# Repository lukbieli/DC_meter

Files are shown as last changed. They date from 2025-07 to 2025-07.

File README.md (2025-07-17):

# DC Meter Project (INA219 + ESP32 + OLED + Button)

A complete open-source DC meter for low-power device development, based on ESP32, three INA219 sensors, SSD1306 OLED display, and a capacitive touch button (TTP233).  
Includes firmware, 3D printable enclosure, wiring diagrams, and ready-to-use SerialPlot configuration files.

---

## Features

- Measures voltage, current, and power on up to 3 channels using INA219 sensors.
- Configurable measurement channels (enable/disable voltage, current, power per channel).
- OLED display (SSD1306 64x48) for live readings and demo mode.
- Capacitive touch button (TTP233) for user interaction (mode/channel switching).
- UART communication for data output and command input.
- Supports both raw binary and ASCII print modes for measurement data.
- Periodic measurement with configurable timer period.
- FreeRTOS-based multitasking for measurement and communication.
- Easily configurable I2C pins and addresses via `menuconfig`.
- Optional auto-configuration of INA219 gain and voltage range.
- SerialPlot integration with ready-to-use `.ini` settings files.
- 3D printable enclosure (STL/3MF for Bambu Studio).

    This project supports up to max 1kHz sampling with only one channel enabled.
---

## Bill of Materials (BOM)

| Qty | Part | Description | Link  |
|-----|---|---|---|
| 1 | ESP32 DEVKIT V1 | Main MCU board | [ESP32 DEVKIT V1](https://pl.aliexpress.com/item/1005008127727230.html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) |
| 2 | INA219 Module | Current sensor | [INA219 Module](https://pl.aliexpress.com/item/1005007533576335.html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) |
| 3 | SSD1306 OLED 64x48 | Display (I2C) | [SSD1306 OLED 64x48](https://pl.aliexpress.com/item/1005009104650988.html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) |
| 4 | TTP233 Capacitive Button | Touch button (digital out) | [TTP233](https://pl.aliexpress.com/item/1005007480801162.html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) |
| 5 | 3D Printed Enclosure | STL/3MF files provided | [3D Model](https://cad.onshape.com/documents/d86296f212e362e831ebef51/w/36947445886156c88ad6d59d/e/d64ef3975a24c979aa83f3d0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) |

---

## Wiring & Connections

### ESP32 Pinout

| Signal | ESP32 Pin | Module/Part |
|---|---|---|
| I2C SDA | GPIO 18 | OLED |
| I2C SCL | GPIO 19 | OLED |
| I2C SDA | GPIO 22 | INA219s |
| I2C SCL | GPIO 21 | INA219s |
| Button | GPIO 34 | TTP233 OUT |
| OLED VCC/GND| 3V3/GND | ESP32 |
| INA219 VCC/GND | 3V3/GND | ESP32 |

**Note:**  
- Project uses separate I2C buses to povide conflicts on I2C when measurement period is very small.
- Connect all INA219 to one I2C and OLED to second one.
- Use pull-up resistors (typically 4.7kΩ) on SDA/SCL if not present on modules.
- TTP233 OUT connects to ESP32 GPIO 34 (digital input).

### Example Wiring Diagram

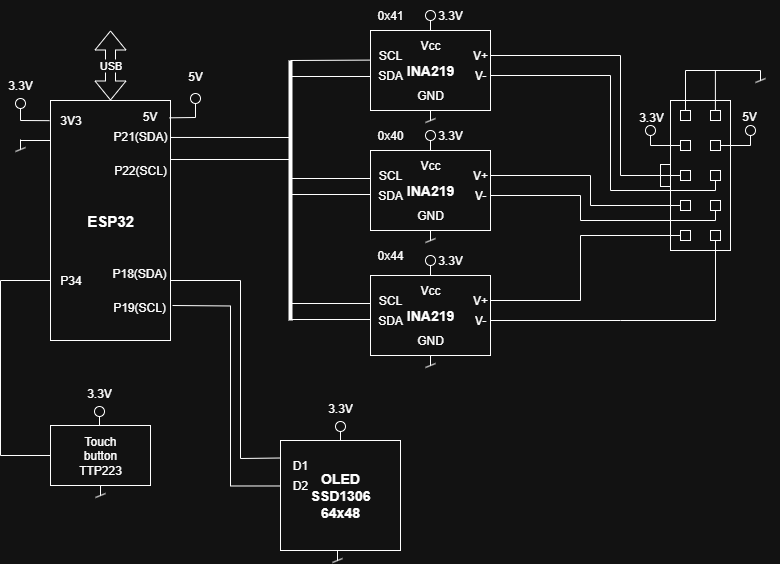
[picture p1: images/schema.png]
Wiring Diagram


---

## Enclosure & 3D Models

- Enclosure designed for ESP32 DEVKIT V1, SSD1306 OLED (64x48), and TTP233 button.
- STL and 3MF files included for Bambu Studio and other slicers.
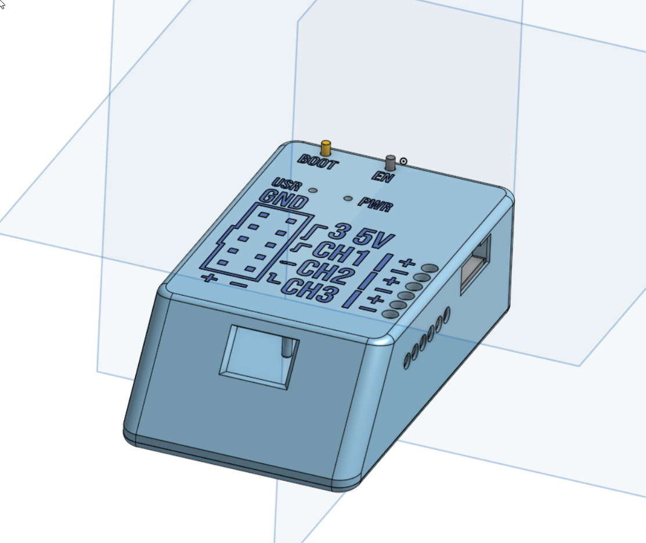
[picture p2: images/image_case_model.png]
3D Model Preview

- [Download 3MF for Bambu Studio](case_model/DC_Meter_Case.3mf)
- [Model available on Onshape.com](https://cad.onshape.com/documents/d86296f212e362e831ebef51/w/36947445886156c88ad6d59d/e/d64ef3975a24c979aa83f3d0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)

---

## SerialPlot Integration

- Ready-to-use SerialPlot `.ini` settings files included:
  - `serialplot/sett_ch9_vcp_default.ini` (raw mode)
  - `serialplot/sett_ch9_vcp_default_ascii.ini` (ASCII mode)
  - `serialplot/sett_ch1_vcp.ini` (single channel example)
- These files configure SerialPlot for live visualization of all channels.
- See [SerialPlot](https://serialplot.org/) for installation.

---

## Firmware Usage

1. **Configure the project** using `idf.py menuconfig`:
    - Set I2C pins, INA219 addresses, shunt resistor value, and LCD options if needed.
2. **Build and flash the firmware**:
    ```sh
    idf.py build
    idf.py flash monitor
    ```
3. **Connect SerialPlot** using the provided `.ini` files for live data plotting.
4. **Button Functions**:
    - Short press: Switch channel (in normal mode).
    - Long press: Switch display mode (demo/normal).

---

## UART Protocol Details

The device communicates over UART using a simple binary protocol for both commands and data.

### Data Output

- **Raw Binary Mode:**  
  Each message starts with two header bytes (`0xAA`, `0xBB`), followed by a length byte, and then the measurement data.  
  The data fields and their order depend on the enabled configuration for each channel (voltage, current, power).  
  - Header: `0xAA 0xBB`
  - Length: Number of data bytes following the header (excluding header and length byte)
  - Data: Floats (4 bytes each) for enabled measurements, in channel order (ch1, ch2, ch3)
- **ASCII Mode:**  
  Each measurement is printed as a comma-separated line of floats:  
  ```
  V1, I1, P1, V2, I2, P2, V3, I3, P3
  ```
  Only enabled measurements are printed.

### Command Input

Commands are sent as binary messages. The first byte is the command type, followed by command-specific data.

| Command Name | Code (hex) | Payload Format | Description |
|---|---|---|---|
| Start/Stop | 0x0A | `[0x0A, 0x01]` or `[0x0A, 0x00]` or `[0x0A, 0x02]` | Start (`0x01`), stop (`0x00`), or start without auto-config (`0x02`) |
| Set Timer Period | 0x0B | `[0x0B, <u8>, <u8>, <u8>, <u8>]`| Set period in microseconds (little-endian)  |
| Set Print Mode | 0x0C | `[0x0C, 0x00]` or `[0x0C, 0x01]`| Raw (`0x00`) or ASCII (`0x01`) output |
| Channel Config | 0x0D | `[0x0D, <ch1>, <cfg1>, <ch2>, <cfg2>, <ch3>, <cfg3>]` | Set channel configuration. See below. |
| Status | 0x0E | `[0x0E]` | Query current status/config |
| Display Mode | 0x0F | `[0x0F, 0x00/0x01]` | Set display mode (normal/demo) |

**Channel Config Bytes:**  
Each channel config consists of two bytes:
- `<chX>`: Bit 0: Voltage enable, Bit 1: Current enable, Bit 2: Power enable
- `<cfgX>`: 
    - Bits 0-1: Gain (0=1, 1=0.5, 2=0.25, 3=0.125)
    - Bit 2: Bus voltage range (0=16V, 1=32V)
    - Bits 4-7: Bus voltage resolution (see `ina219.h` for values)

Example:  
To enable voltage and current for channel 1, only current for channel 2, and all for channel 3:  
`[0x0D, 0x03, 0x10, 0x02, 0x10, 0x07, 0x10]`  
- ch1: 0x03 = 0b011 (voltage+current), 0x10 = gain/resolution config
- ch2: 0x02 = 0b010 (current), 0x10 = gain/resolution config
- ch3: 0x07 = 0b111 (all enabled), 0x10 = gain/resolution config

---

## Images

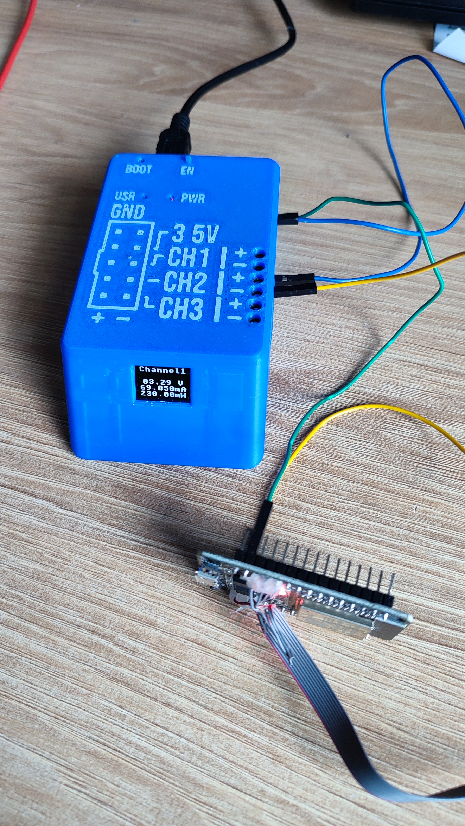
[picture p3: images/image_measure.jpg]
Device Assembled
- 
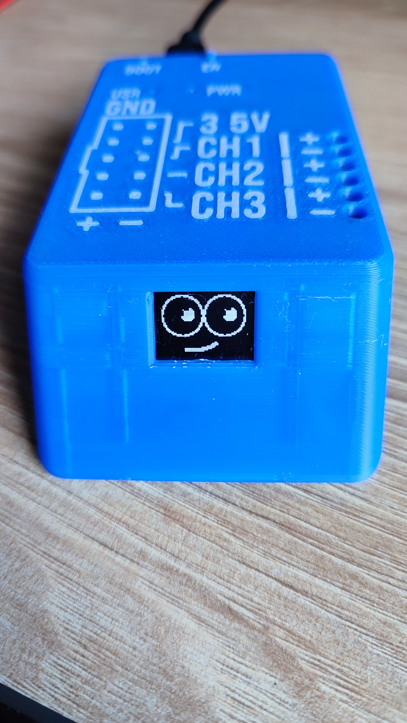
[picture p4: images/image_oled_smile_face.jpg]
OLED Demo Mode
- 
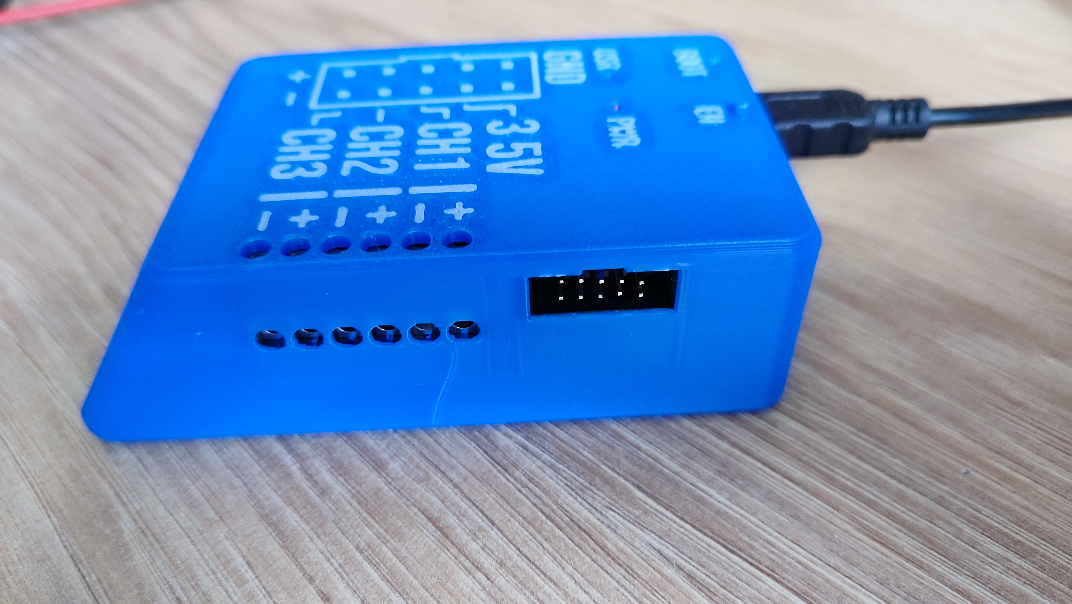
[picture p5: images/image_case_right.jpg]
Right side of case
- 
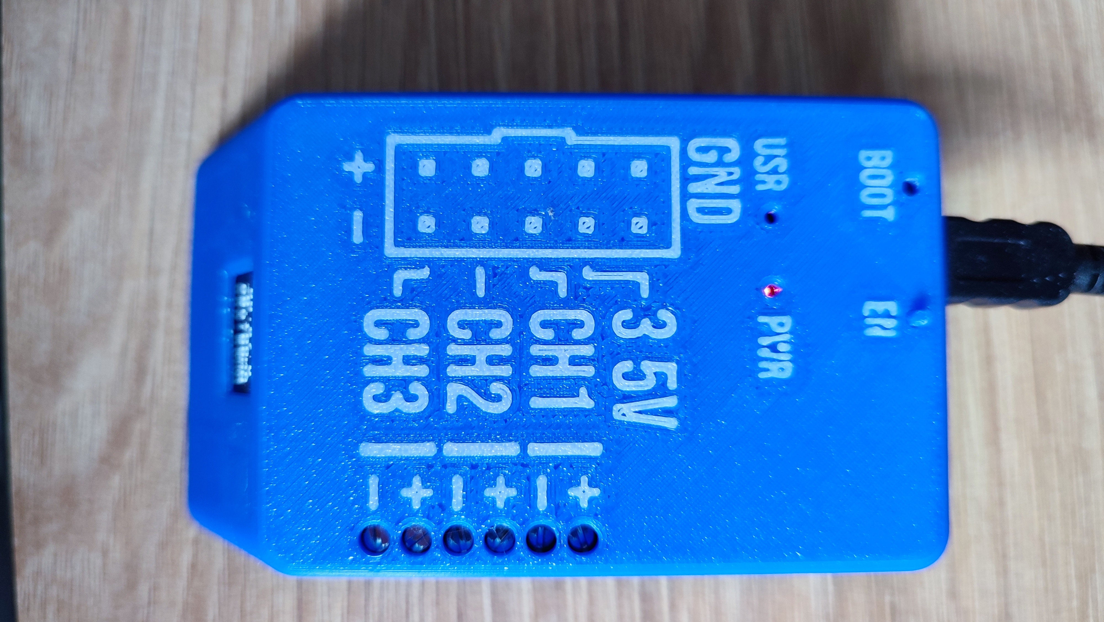
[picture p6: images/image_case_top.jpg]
Top of case
- 
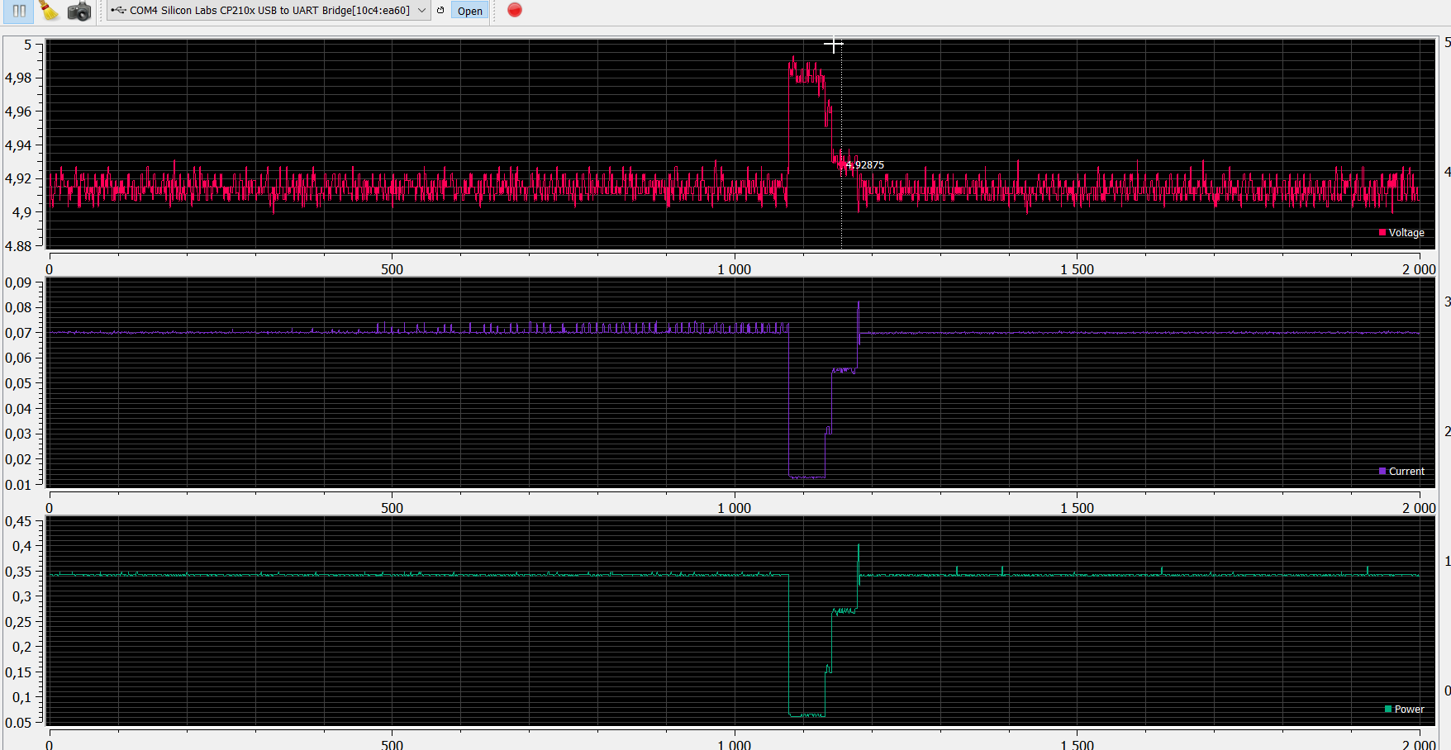
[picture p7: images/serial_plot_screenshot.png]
SerialPlot Screenshot
- 

---

## File Structure

- `main.c` - Application entry point.
- `CurrentDrv.c/h` - INA219 driver and measurement logic.
- `CommM.c/h` - UART communication and command handling.
- `DisplayM.c/h` - OLED display and button logic.
- `serialplot/` - SerialPlot settings files (`.ini`).
- `models/` - 3D models and 3MF file for enclosure.
- `images/` - Photos, wiring diagrams, screenshots.
- `Kconfig.projbuild` - Project configuration options.
- `idf_component.yml` - Component dependencies.

---

## License

This project is licensed under the [MIT License](LICENSE).  
You are free to use, modify, and distribute this software for any purpose, including commercial use, as long as you include the original copyright.

---

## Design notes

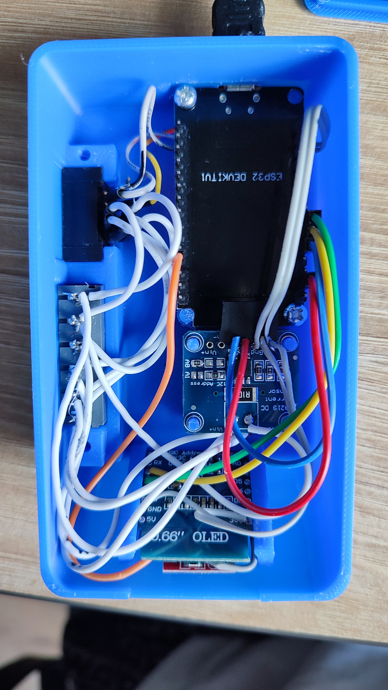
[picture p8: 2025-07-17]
images/image_inside.jpg

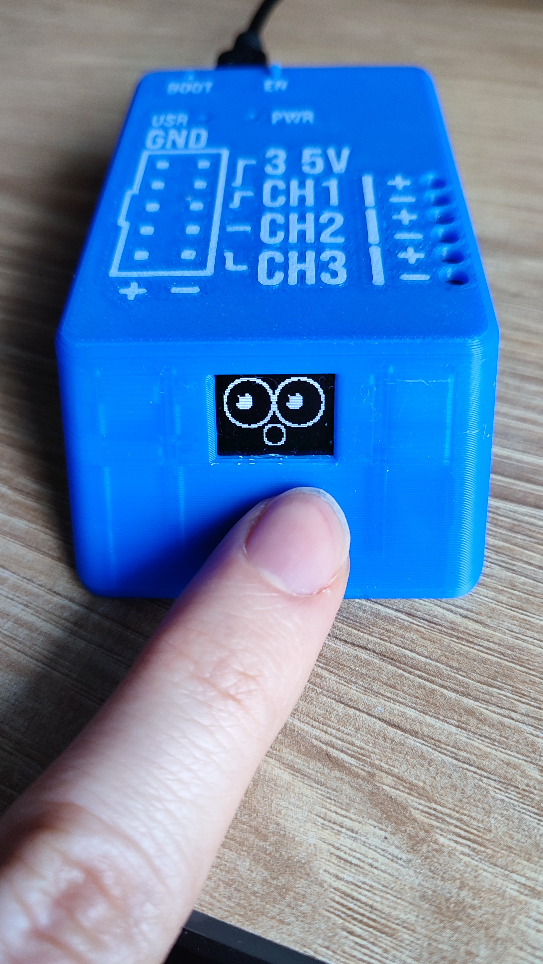
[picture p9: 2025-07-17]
images/image_oled_suprised_face.jpg

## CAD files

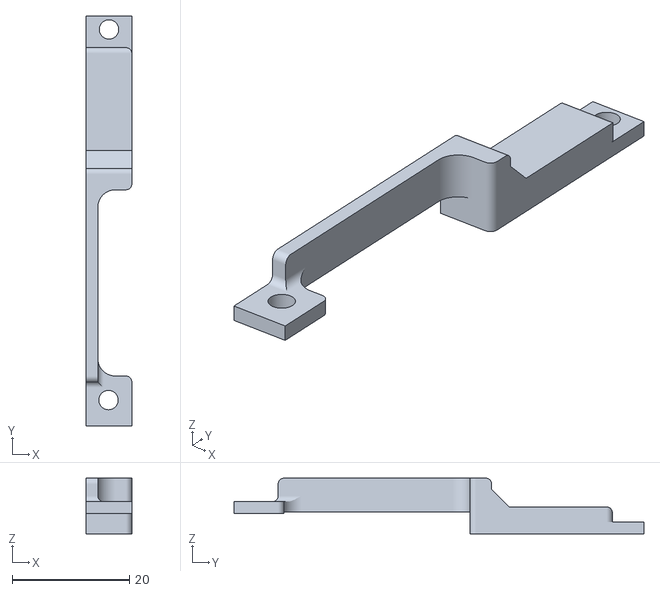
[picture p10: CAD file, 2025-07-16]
case_model/DC_Meter_Case - Holder.stl
7.80 x 70.0 x 9.50

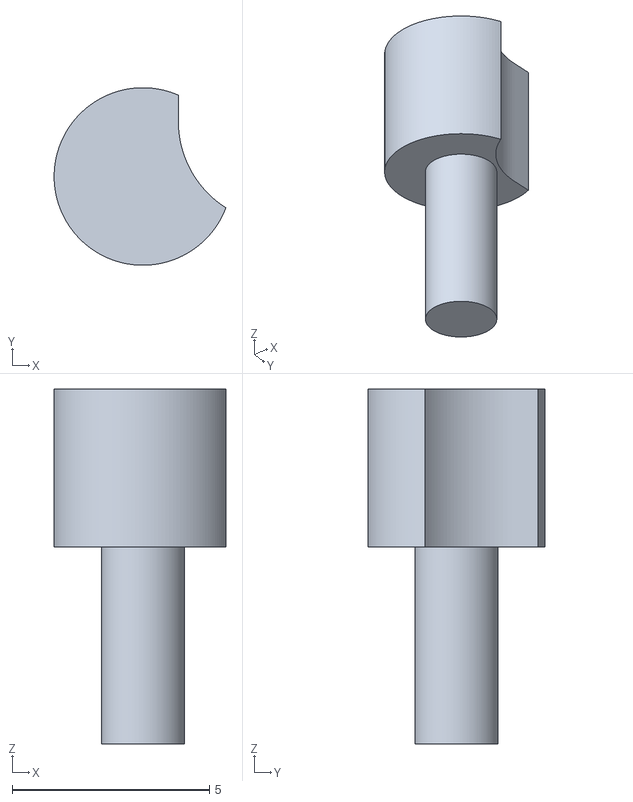
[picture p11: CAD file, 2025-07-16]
case_model/DC_Meter_Case - Button1.stl
4.35 x 4.50 x 9.00

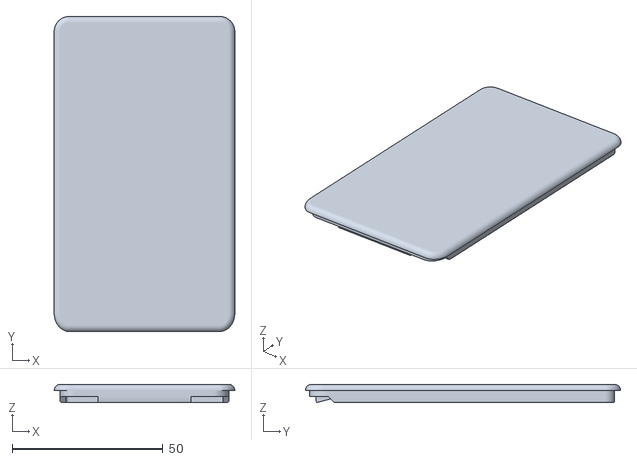
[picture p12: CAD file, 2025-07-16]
case_model/DC_Meter_Case - Lid.stl
60.0 x 104.6 x 6.09

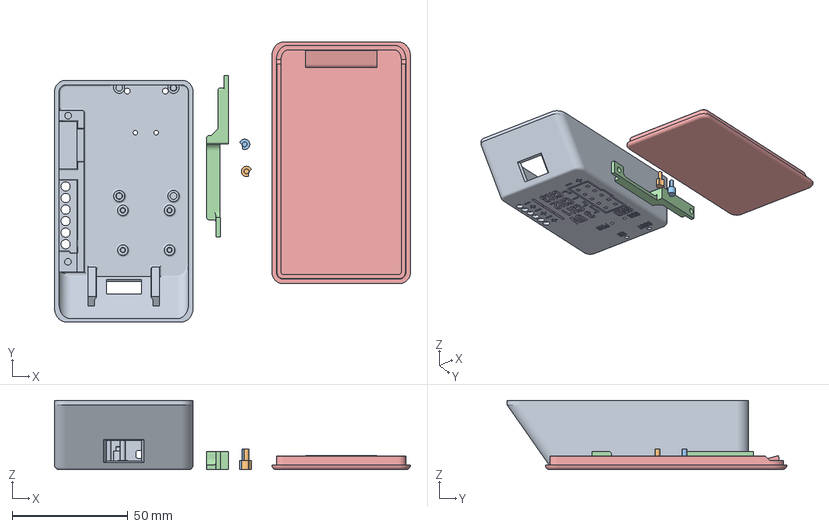
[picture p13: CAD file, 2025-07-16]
case_model/DC_Meter_Case.3mf
154.1 x 121.1 x 30.0 mm
DC_Meter_Case - Bottom.stl
DC_Meter_Case - Button1.stl
DC_Meter_Case - Button2.stl
DC_Meter_Case - Holder.stl
DC_Meter_Case - Lid.stl
Text

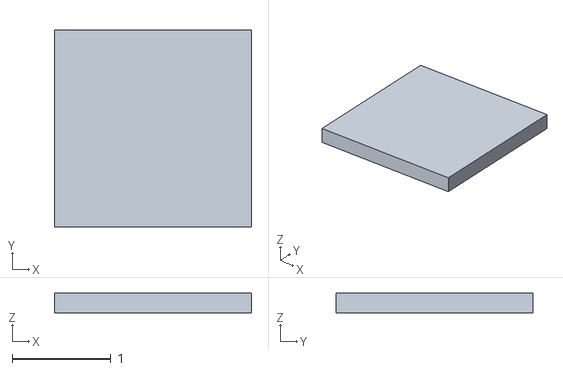
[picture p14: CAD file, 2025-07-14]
case_model/DC_Meter_Case - Surface 8.stl
2.00 x 2.00 x 0.2

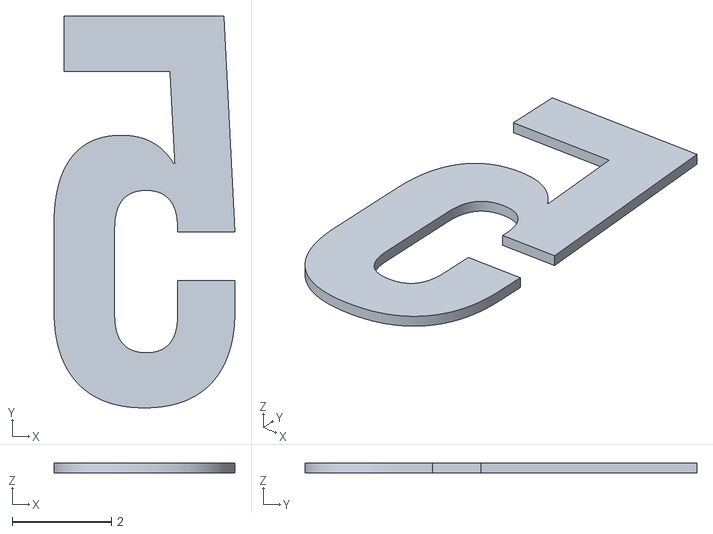
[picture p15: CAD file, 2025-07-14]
case_model/DC_Meter_Case - Surface 45.stl
3.64 x 7.89 x 0.2

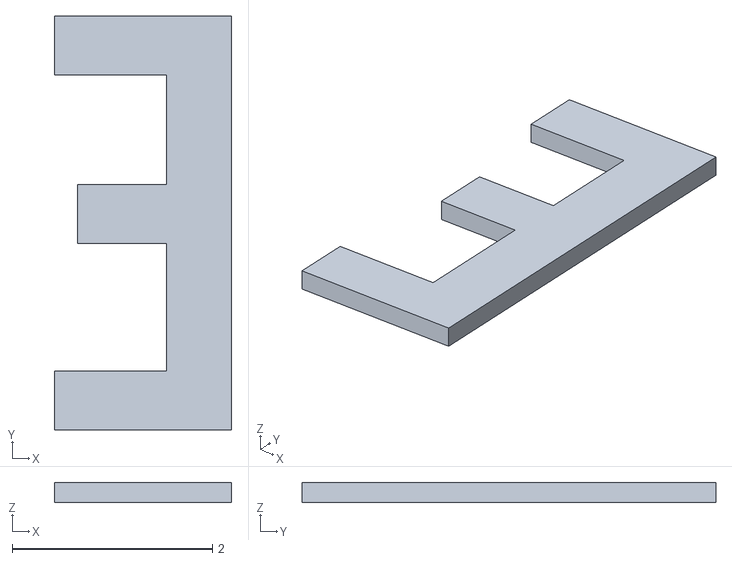
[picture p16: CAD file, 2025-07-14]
case_model/DC_Meter_Case - Surface 38.stl
1.77 x 4.14 x 0.2

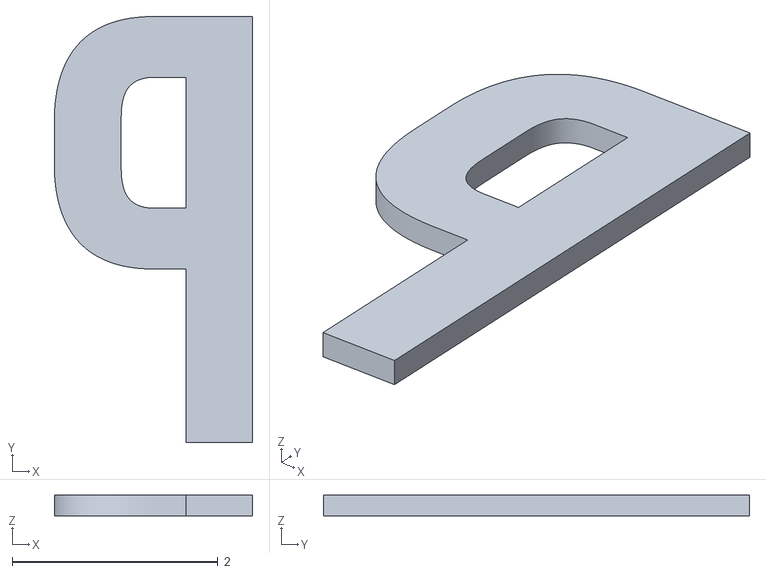
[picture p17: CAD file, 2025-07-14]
case_model/DC_Meter_Case - Surface 51.stl
1.93 x 4.14 x 0.2

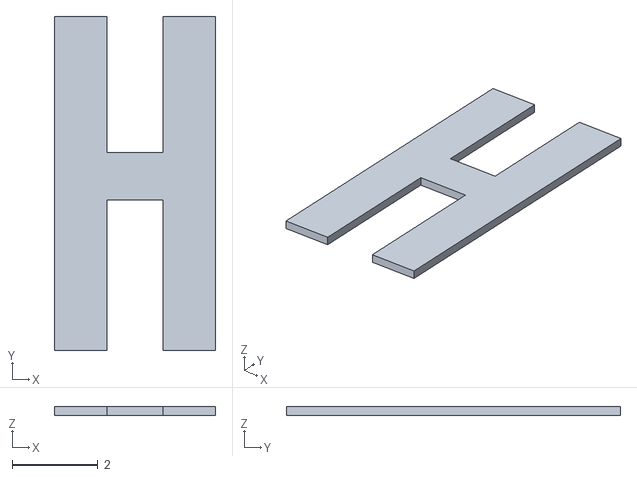
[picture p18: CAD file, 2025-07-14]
case_model/DC_Meter_Case - Surface 42.stl
3.76 x 7.78 x 0.2

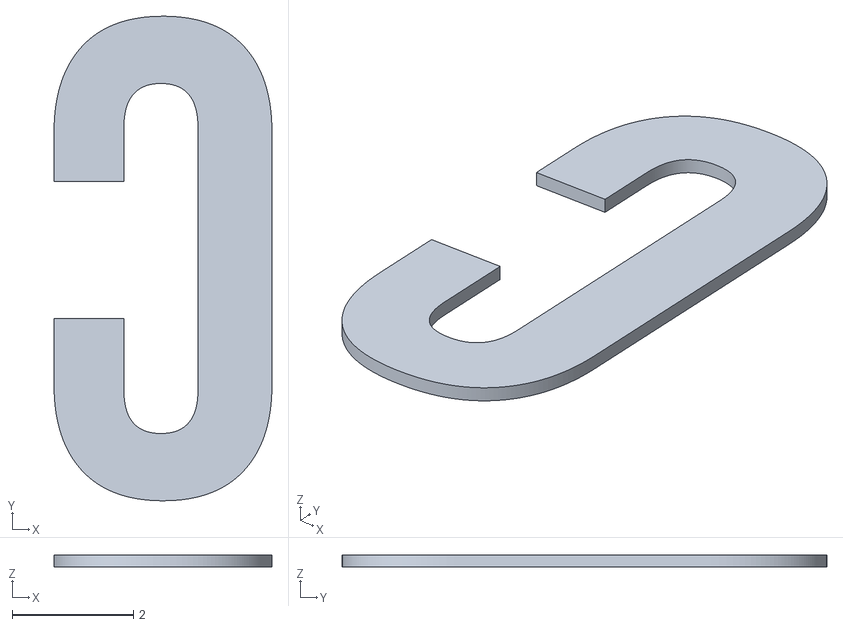
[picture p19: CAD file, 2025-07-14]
case_model/DC_Meter_Case - Surface 3.stl
3.60 x 8.00 x 0.2

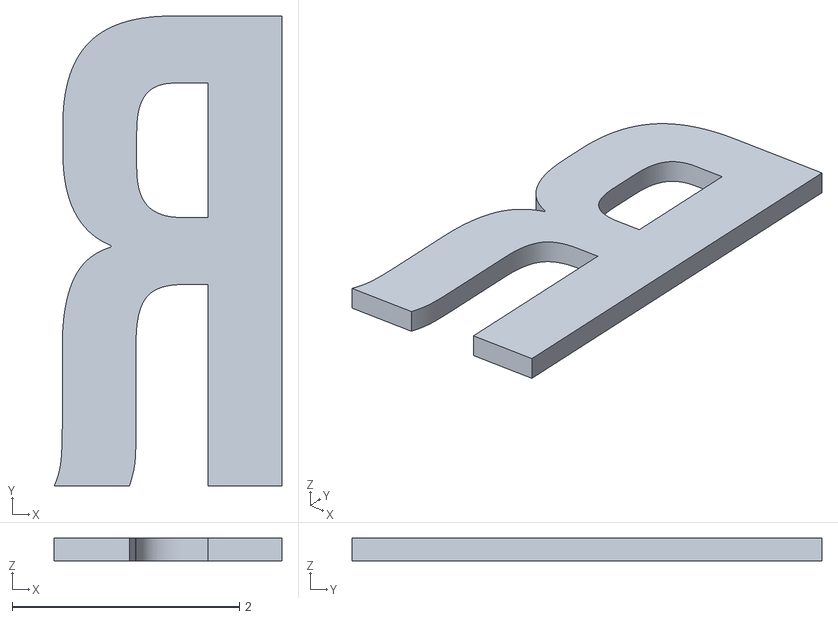
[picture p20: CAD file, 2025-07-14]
case_model/DC_Meter_Case - Surface 26.stl
2.00 x 4.14 x 0.2

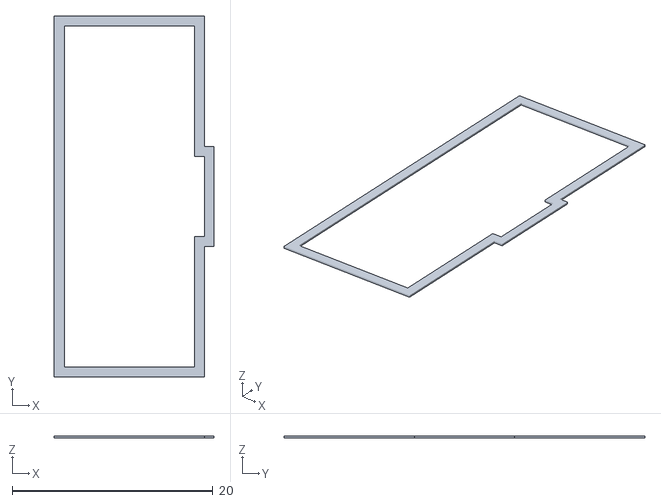
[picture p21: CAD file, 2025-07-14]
case_model/DC_Meter_Case - Surface 4.stl
15.9 x 36.0 x 0.2

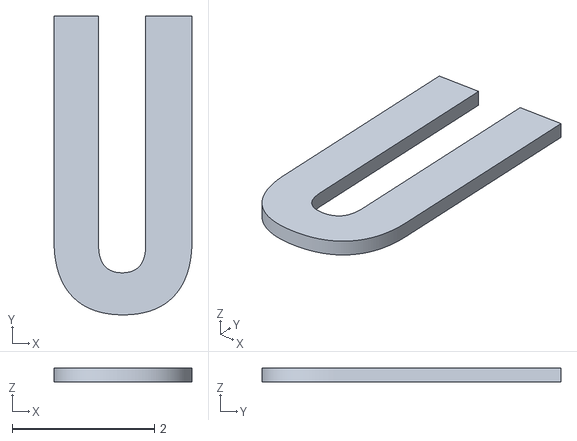
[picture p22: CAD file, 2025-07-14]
case_model/DC_Meter_Case - Surface 57.stl
1.94 x 4.20 x 0.2

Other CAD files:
case_model/DC_Meter_Case - Button2.stl
case_model/DC_Meter_Case - Surface 15.stl
case_model/DC_Meter_Case - Surface 55.stl
case_model/DC_Meter_Case - Surface 22.stl
case_model/DC_Meter_Case - Surface 43.stl
case_model/DC_Meter_Case - Surface 1.stl
case_model/DC_Meter_Case - Surface 10.stl
case_model/DC_Meter_Case - Surface 11.stl
case_model/DC_Meter_Case - Surface 12.stl
case_model/DC_Meter_Case - Surface 13.stl
case_model/DC_Meter_Case - Surface 14.stl
case_model/DC_Meter_Case - Surface 16.stl
case_model/DC_Meter_Case - Surface 2.stl
case_model/DC_Meter_Case - Surface 21.stl
case_model/DC_Meter_Case - Surface 23.stl
case_model/DC_Meter_Case - Surface 24.stl
case_model/DC_Meter_Case - Surface 25.stl
case_model/DC_Meter_Case - Surface 27.stl
case_model/DC_Meter_Case - Surface 28.stl
case_model/DC_Meter_Case - Surface 29.stl
case_model/DC_Meter_Case - Surface 30.stl
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

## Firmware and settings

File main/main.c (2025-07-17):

// SPDX-License-Identifier: MIT
// Copyright (c) 2025 Lukasz Bielinski

#include <stdio.h>
#include <freertos/FreeRTOS.h>
#include <freertos/task.h>
#include <freertos/queue.h>
#include <ina219.h>
#include <string.h>
#include <esp_log.h>
#include <assert.h>

#include <driver/gpio.h>
#include <driver/uart.h>

#include <esp_timer.h>

#include "CommM.h"
#include "CurrentDrv.h"
#include "DisplayM.h"


const static char *TAG = "DC_Meter";


void app_main()
{


    ESP_ERROR_CHECK(i2cdev_init());
    xTaskCreate(CurrentDrv_Task, "CurrentDrv_Task", configMINIMAL_STACK_SIZE * 8, NULL, 5, NULL);

    xTaskCreate(CommM_Task, "CommM_Task", configMINIMAL_STACK_SIZE * 8, NULL, 4, NULL);

    DisplayM_Init();
}

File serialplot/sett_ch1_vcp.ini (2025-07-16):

[MainWindow]
size=@Size(2132 1236)
pos=@Point(874 282)
activePanel=Commands
hidePanels=false
maximized=false
state=@ByteArray(\0\0\0\xff\0\0\0\0\xfd\0\0\0\0\0\0\bT\0\0\x4y\0\0\0\x4\0\0\0\x4\0\0\0\b\0\0\0\b\xfc\0\0\0\x1\0\0\0\x2\0\0\0\x3\0\0\0\f\0t\0\x62\0P\0l\0o\0t\x1\0\0\0\0\xff\xff\xff\xff\0\0\0\0\0\0\0\0\0\0\0\x1a\0t\0\x62\0P\0o\0r\0t\0\x43\0o\0n\0t\0r\0o\0l\x1\0\0\0}\xff\xff\xff\xff\0\0\0\0\0\0\0\0\0\0\0\x10\0t\0\x62\0R\0\x65\0\x63\0o\0r\0\x64\x1\0\0\x2Y\xff\xff\xff\xff\0\0\0\0\0\0\0\0)

[Port]
selectedPort=COM4
baudRate=256000
parity=none
dataBits=8
stopBits=1
flowControl=none

[DataFormat]
format=custom

[DataFormat_Binary]
numOfChannels=9
numberFormat=float
endianness=little

[DataFormat_ASCII]
numOfChannels=9
delimiter=","
customDelimiter=|
filterMode=disabled
filterPrefix=

[DataFormat_CustomFrame]
numOfChannels=3
numberFormat=float
endianness=little
frameStart=AA BB
fixedSize=false
frameSize=1
checksum=false
debugMode=true

[Channels]
channel\1\name=Voltage
channel\1\color=@Variant(\0\0\0\x43\x1\xff\xff\xff\xff\0\0VV\0\0)
channel\1\visible=true
channel\1\gain=1
channel\1\gainEnabled=false
channel\1\offset=0
channel\1\offsetEnabled=false
channel\2\name=Current
channel\2\color=@Variant(\0\0\0\x43\x1\xff\xff~~--\xd2\xd2\0\0)
channel\2\visible=true
channel\2\gain=1
channel\2\gainEnabled=false
channel\2\offset=0
channel\2\offsetEnabled=false
channel\3\name=Power
channel\3\color=@Variant(\0\0\0\x43\x1\xff\xff\0\0\xae\xae~~\0\0)
channel\3\visible=true
channel\3\gain=1
channel\3\gainEnabled=false
channel\3\offset=0
channel\3\offsetEnabled=false
channel\4\name=Voltage2
channel\4\color=@Variant(\0\0\0\x43\x1\xff\xff\xfe\xfe\x89\x89\0\0\0\0)
channel\4\visible=true
channel\4\gain=1
channel\4\gainEnabled=false
channel\4\offset=0
channel\4\offsetEnabled=false
channel\5\name=Current2
channel\5\color=@Variant(\0\0\0\x43\x1\xff\xff\0\0\xaa\xaa\xff\xff\0\0)
channel\5\visible=true
channel\5\gain=1
channel\5\gainEnabled=false
channel\5\offset=0
channel\5\offsetEnabled=false
channel\6\name=Power2
channel\6\color=@Variant(\0\0\0\x43\x1\xff\xffjj\x82\x82ll\0\0)
channel\6\visible=true
channel\6\gain=1
channel\6\gainEnabled=false
channel\6\offset=0
channel\6\offsetEnabled=false
channel\7\name=Voltage3
channel\7\color=@Variant(\0\0\0\x43\x1\xff\xff\xff\xff\x2\x2\x9d\x9d\0\0)
channel\7\visible=true
channel\7\gain=1
channel\7\gainEnabled=false
channel\7\offset=0
channel\7\offsetEnabled=false
channel\8\name=Current3
channel\8\color=@Variant(\0\0\0\x43\x1\xff\xff\0\0\xb9\xb9\x17\x17\0\0)
channel\8\visible=true
channel\8\gain=1
channel\8\gainEnabled=false
channel\8\offset=0
channel\8\offsetEnabled=false
channel\9\name=Power3
channel\9\color=@Variant(\0\0\0\x43\x1\xff\xffzzGG\x82\x82\0\0)
channel\9\visible=true
channel\9\gain=1
channel\9\gainEnabled=false
channel\9\offset=0
channel\9\offsetEnabled=false
channel\size=9

[Plot]
numOfSamples=2000
plotWidth=2000
indexAsX=true
xMax=1000
xMin=0
autoScale=true
yMax=1000
yMin=0
darkBackground=true
grid=true
minorGrid=true
legend=true
multiPlot=true
symbols=auto
numLines=1000
decimals=3

[Commands]
command\1\name=MODE (stop/start)
command\1\type=hex
command\1\data=0A 01
command\2\name=TIME (us LE)
command\2\type=hex
command\2\data=0B B8 0B 00 00
command\3\name=Print (Raw/Ascii)
command\3\type=hex
command\3\data=0C 00
command\4\name=Config
command\4\type=hex
command\4\data=0D 07 30 00 30 00 30
command\5\name=Status
command\5\type=hex
command\5\data=0E
command\6\name=Command 7
command\6\type=hex
command\6\data=0D 07 D0 07 D0 07 D0
command\7\name=Display (Norm/Demo)
command\7\type=hex
command\7\data=0F 01
command\size=7

[Record]
autoIncrement=true
recordPaused=true
stopOnClose=true
header=true
disableBuffering=false
separator=","
decimals=6
timestamp=true
timestampFormat=milliseconds

[UpdateCheck]
periodicCheck=true
lastCheck=2025-07-16

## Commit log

2025-07-03 Update README.md to provide detailed project description, features, usage instructions, and UART command protocols for the DC Meter with INA219 and ESP-IDF.
2025-07-10 Enhance INA219 driver with auto-configuration and averaging features
    - Introduced a new structure for channel instances to manage multiple INA219 sensors.
    - Implemented auto-configuration based on voltage and current readings.
    - Added averaging functionality for smoother data output.
    - Updated channel configuration handling to support new features.
    - Modified UART command handling to accommodate new configuration commands.
2025-07-14 Add multiple STL files for DC Meter Case parts and update serialplot configurations
    - Added new STL files for DC Meter Case parts 2 to 54.
    - Introduced new executable and configuration files for serialplot.
    - Created settings files for different channel configurations and data formats.
    - Updated command settings for serialplot to enhance functionality.
    [DC_Meter_Case - Button1.stl, DC_Meter_Case - Button2.stl, DC_Meter_Case - Lid.stl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]
2025-07-16 feat: Integrate display module and update communication handling
    - Added DisplayM module for managing display functionalities.
    - Implemented display command handling in CommM.c to enable demo mode.
    - Updated CurrentDrv to include a function for retrieving averaged data.
    - Removed obsolete lvgl_demo_ui.c file and integrated its functionality into DisplayM.
    - Updated CMakeLists.txt to register DisplayM.c and its header.
    - Adjusted main.c to initialize the display module during application startup.
2025-07-16 feat: Add new STL files for DC Meter Case components and update serialplot configurations
    [DC_Meter_Case - Button1.stl, DC_Meter_Case - Button2.stl, DC_Meter_Case - Holder.stl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]
2025-07-17 replaced custom esp-idf-lib struct with local one
    [CurrentDrv.c]
